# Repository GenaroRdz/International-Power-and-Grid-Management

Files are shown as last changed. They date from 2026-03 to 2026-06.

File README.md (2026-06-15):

# ⚡ Design and Implementation of Mechatronic Systems: ECU Test Bench





This repository contains all the code, hardware schematics, and assets used for the class **Design and Implementation of Mechatronic Systems**. 

The core of this project is a **High-Current Load Controller (ECU Test Bench)** designed to safely simulate, control, and monitor high-power loads (12V/5A) using solid-state switching and a custom Python Graphical User Interface (GUI).

---# ⚡ Automated HIL Power & Grid Management Unit

> **Solid-State ECU Test Bench for Automotive Hardware-In-the-Loop (HIL) Validation**

This repository contains the firmware, host software, hardware schematics, and testing assets developed for the *Design and Implementation of Mechatronic Systems* engineering capstone. 

The core of this project is a **High-Current Power Management Unit (PMU)** designed to safely automate the power cycling, control, and real-time monitoring of automotive Electronic Control Units (ECUs). By replacing traditional mechanical relays and manual resets with a fully automated, VISA-compliant Python GUI and a solid-state switching matrix, this system provides a robust framework for continuous ECU stress-testing.

## 📋 System Architecture

The architecture relies on a strict separation of concerns across three layers, safely isolating the low-voltage logic control (3.3V) from the raw automotive power stage (12V) using galvanic isolation.

1. **Host Layer (PC / Python):** A robust GUI that manages serial connection watchdogs, visualizes live telemetry on an oscilloscope, and parses automation scripts (e.g., `LOOP 10`, `DELAY 100`) into single-line SCPI/VISA string commands (`*IDN?`, `ECU1_BAT ON`).
2. **Control Layer (ESP32 / MicroPython):** An asynchronous event-driven firmware (`asyncio`) that parses commands, manages GPIO logic, polls I2C sensors, and controls the SPI CAN bus simultaneously without blocking the main loop.
3. **Hardware Layer (Custom PCB):** A 12-channel power delivery matrix protecting the logic domain from automotive 12V inrush currents and inductive spikes.

## 🚀 Key Features & Core Components

* **Solid-State Power Matrix:** Independent 12V/5A control over Battery (BAT), Accessory (ACC), and Ignition (IGN) lines across 4 distinct ECU channels.
  * *Component:* P-Channel Power MOSFETs (IRF4905) driven by PC817 Optocouplers.
* **Real-Time I2C Telemetry:** Closed-loop monitoring of voltage, current, and power consumption per channel using custom bare-metal I2C drivers.
  * *Component:* INA226 digital power monitors with ultra-low 0.01Ω shunt resistors and hardware-configured I2C addresses.
* **CAN Bus Integration:** SPI-driven CAN controller integration for broadcast messaging, ECU node-health supervision, and live traffic monitoring via the GUI.
  * *Component:* MCP2515 CAN Controller + TJA1050 Transceiver.
* **Automated Sequencer:** Custom scripting engine allowing the execution of complex testing vectors (e.g. stress tests) directly from `.txt` files.

## 📂 Repository Structure

* `/Firmware`: MicroPython scripts for the ESP32 (main asynchronous loop, custom `INA226.py` and `mcp2515.py` register-level drivers, command parser).
* `/Software`: Python GUI application (Tkinter), live scope plotting, CAN monitor, and serial management.
* `/Hardware`: KiCad schematics, wiring diagrams, LTspice validation simulations (`.asc`, `.model`), and Bill of Materials (BOM).
* `/Tests`: Example sequence `.txt` files for automated stress testing (e.g., `COMPLETE Test.txt`).
* `/Docs`: Final Technical Report, architecture diagrams, and component datasheets.

## 🛠️ Setup and Installation

### 1. Hardware Assembly
Assemble the physical circuit following the schematics provided in the `/Hardware` folder.
> ⚠️ **Safety Warning:** This system handles cumulative currents capable of exceeding 15A during inrush events. Ensure the use of appropriate gauge wiring (AWG 16 minimum) for the 12V power bus, use proper thermal dissipation techniques, and include a master inline fuse & kill-switch before the MOSFET array.

### 2. Firmware (ESP32)
1. Flash the ESP32 microcontroller with the latest MicroPython firmware.
2. Upload all python scripts from the `/Firmware` folder to the board using tools like Thonny IDE or `mpremote`.
3. The board will automatically execute `main.py` on boot, initialize the SPI/I2C buses, and await serial commands at `115200` bauds.

### 3. Software (Python GUI)
The host control interface requires **Python 3.13.x**. Navigate to the software folder and install the required dependencies:

```bash
cd Software
pip install -r requirements.txt
python main.py
```
## 📋 System Architecture

The project is modularly designed, safely isolating the low-voltage logic control (3.3V) from the raw power stage (12V) using optocouplers. 

### Core Components:
* **Microcontroller:** ESP32 running MicroPython.
* **Power Switching:** P-Channel Power MOSFET (IRF4905).
* **Current/Voltage Monitoring:** INA226 (I2C) with an ultra-low shunt resistor.
* **Isolation:** PC817 Optocoupler.
* **Simulated Load:** 120 Ohms Resistors. (in total 12 Resistors ~1.2A drawn).

---

## 📂 Repository Structure

* `/firmware`: MicroPython scripts for the ESP32 (I2C sensor reading, PWM/Digital control).
* `/software`: Python GUI application for remote monitoring and control.
* `/hardware`: Circuit schematics, wiring diagrams, and LTspice simulations (`.asc`, `.model`).
* `/docs`: Final Report, technical documentation and component datasheets (INA226, IRF4905, etc.).

---

## 🛠️ Setup and Installation

### 1. Hardware Assembly
Assemble the physical circuit following the schematics provided in the `/hardware` folder. 
> ⚠️ **Safety Warning:** This system handles currents <= 5A. Ensure the use of appropriate gauge wiring (AWG 16 minimum) for the power stage and include a master kill-switch before the MOSFET array.

### 2. Firmware (ESP32)
Flash the ESP32 with the latest MicroPython firmware. Upload the scripts from the `/firmware` folder to the board using tools like Thonny IDE or `mpremote`.

### 3. Software (Python GUI)
The control interface requires **Python 3.13.xx**. Navigate to the software folder and install the required dependencies:

```bash
cd software
pip install -r requirements.txt
python main.py

Authors:
Genaro Rodríguez Garza - A00831640 
Juan Pablo Carrasco Ferra Martínez - A01252910 
Eduardo de la Rosa Flores - A01039969 
Kleber Andres Molina Yepez - A00838725 
Jose Joaquin Rodriguez Cisneros - A00833104

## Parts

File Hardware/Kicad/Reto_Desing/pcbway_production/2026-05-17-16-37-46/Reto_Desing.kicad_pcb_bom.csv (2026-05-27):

Designator | Quantity | Value | Footprint | Package | MPN | DNP | Mount_Type | Description | KiLib_Generator | Sim.Pins
D1, D2, D3 | 3 | LED | LED_D5.0mm |  |  |  | tht | Light emitting diode | LED/THT | 1=K 2=A
J1, J2, J3, J4, J5, J6 | 6 | Conn_01x02 | JWT_A3963_1x02_P3.96mm_Vertical |  |  |  | tht | Generic connector, single row, 01x02, script generated (kicad-library-utils/schlib/autogen/connector/)
Q1, Q2, Q3 | 3 | IRF4905 | TO-220-3_Vertical |  |  |  | tht | -74A Id, -55V Vds, Single P-Channel HEXFET Power MOSFET, 20mOhm Ron, TO-220AB | package/TO_SOT/THT
R1, R10, R4, R5, R6, R9 | 6 | 330 | R_Axial_DIN0207_L6.3mm_D2.5mm_P10.16mm_Horizontal |  |  |  | tht | Resistor | resistor/THT
R11, R2, R7 | 3 | 10K | R_Axial_DIN0207_L6.3mm_D2.5mm_P10.16mm_Horizontal |  |  |  | tht | Resistor | resistor/THT
R12, R3, R8 | 3 | 120 | R_Axial_DIN0207_L6.3mm_D2.5mm_P10.16mm_Horizontal |  |  |  | tht | Resistor | resistor/THT
U1, U2, U3 | 3 | PC817 | DIP-4_W7.62mm |  |  |  | tht | DC Optocoupler, Vce 35V, CTR 50-300%, DIP-4 | package/DIP/legacy

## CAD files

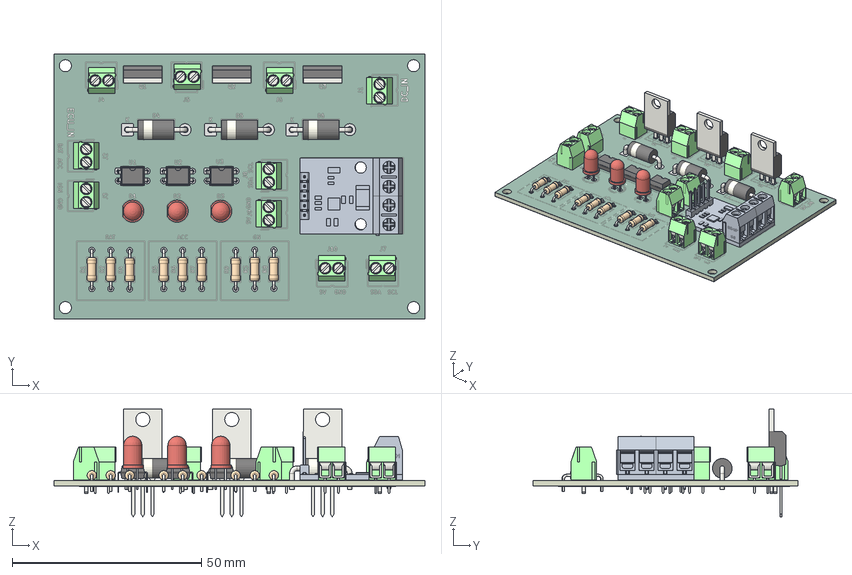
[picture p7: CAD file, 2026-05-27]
Hardware/Kicad/Reto_Desing/PCB_V2.step
98.0 x 70.0 x 28.5 mm
M1.6x4-Screw030 x 10
TO-220-3_Vertical x 3
R_Axial_DIN0207_L6.3mm_D2.5mm_P10.16mm_Horizontal x 9
LED_D5.0mm x 3
D_DO-201AD_P15.24mm_Horizontal x 3
DIP-4_W7.62mm x 3
PCB_V2 1.26.1
Reto_Desing_copper
Reto_Desing_pad
Reto_Desing_silkscreen x 2
Reto_Desing_soldermask x 2
Reto_Desing_PCB

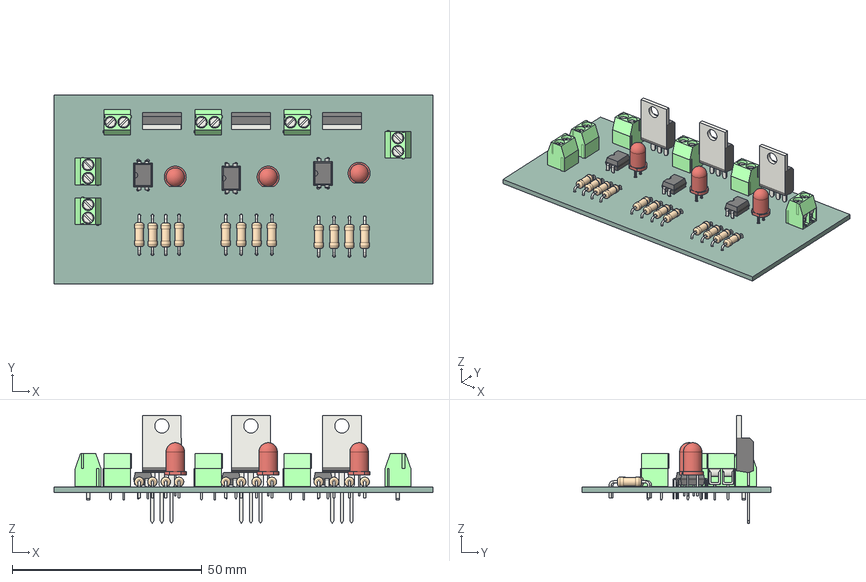
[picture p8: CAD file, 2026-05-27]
Hardware/Kicad/Reto_Desing/.step
100.0 x 50.0 x 28.5 mm
TO-220-3_Vertical x 3
R_Axial_DIN0207_L6.3mm_D2.5mm_P10.16mm_Horizontal x 12
M1.6x4-Screw030 x 6
LED_D5.0mm x 3
DIP-4_W7.62mm x 3
Reto_Desing_PCB

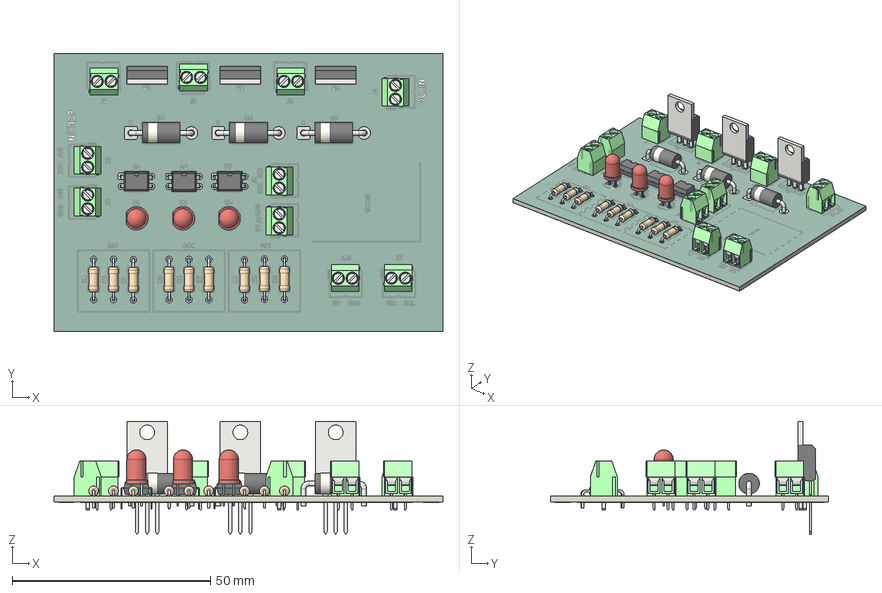
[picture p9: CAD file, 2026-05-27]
Hardware/Kicad/Reto_Desing/PCB.step
98.0 x 70.0 x 28.5 mm
M1.6x4-Screw030 x 10
TO-220-3_Vertical x 3
R_Axial_DIN0207_L6.3mm_D2.5mm_P10.16mm_Horizontal x 9
LED_D5.0mm x 3
D_DO-201AD_P15.24mm_Horizontal x 3
DIP-4_W7.62mm x 3
Reto_Desing_copper
Reto_Desing_pad
Reto_Desing_via
Reto_Desing_silkscreen x 2
Reto_Desing_soldermask x 2
Reto_Desing_PCB

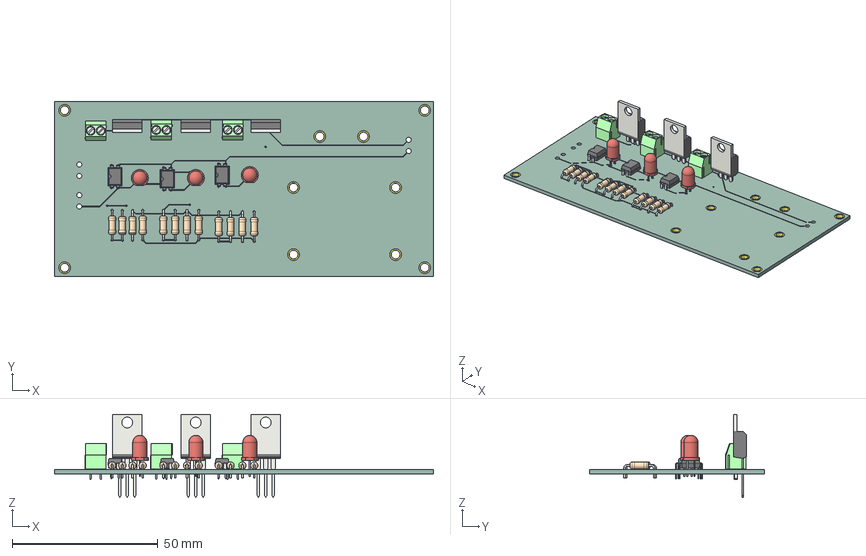
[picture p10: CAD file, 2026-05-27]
Hardware/Kicad/Reto_Desing/Pieza.step
130.0 x 60.0 x 28.5 mm
TO-220-3_Vertical x 3
R_Axial_DIN0207_L6.3mm_D2.5mm_P10.16mm_Horizontal x 12
LED_D5.0mm x 3
M1.6x4-Screw030 x 3
DIP-4_W7.62mm x 3
Reto_Desing_copper
Reto_Desing_via
Reto_Desing_PCB

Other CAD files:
Hardware/Kicad/Reto_Desing/PCB_V1.step

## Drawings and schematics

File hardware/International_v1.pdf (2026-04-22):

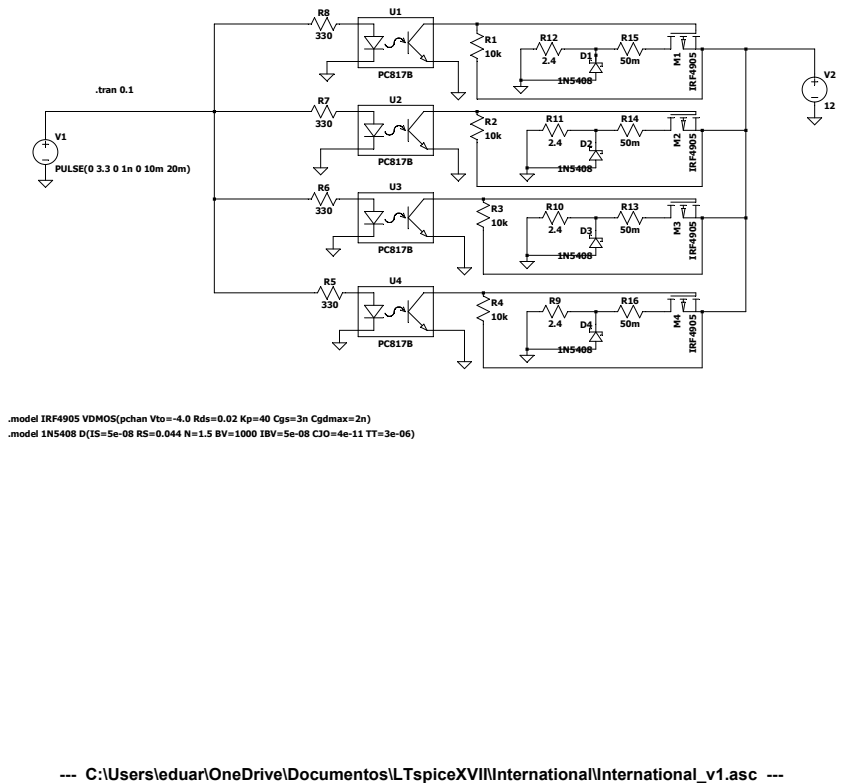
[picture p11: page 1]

2.4 M¹ IRF4905 M² IRF4905 M³ IRF4905 M⁴ IRF4905

.model IRF4905 VDMOS(pchan Vto=-4.0 Rds=0.02 Kp=40 Cgs=3n Cgdmax=2n)
.model 1N5408 D(IS=5e-08 RS=0.044 N=1.5 BV=1000 IBV=5e-08 CJO=4e-11 TT=3e-06)

--- C:\Users\eduar\OneDrive\Documentos\LTspiceXVII\International\International_v1.asc ---

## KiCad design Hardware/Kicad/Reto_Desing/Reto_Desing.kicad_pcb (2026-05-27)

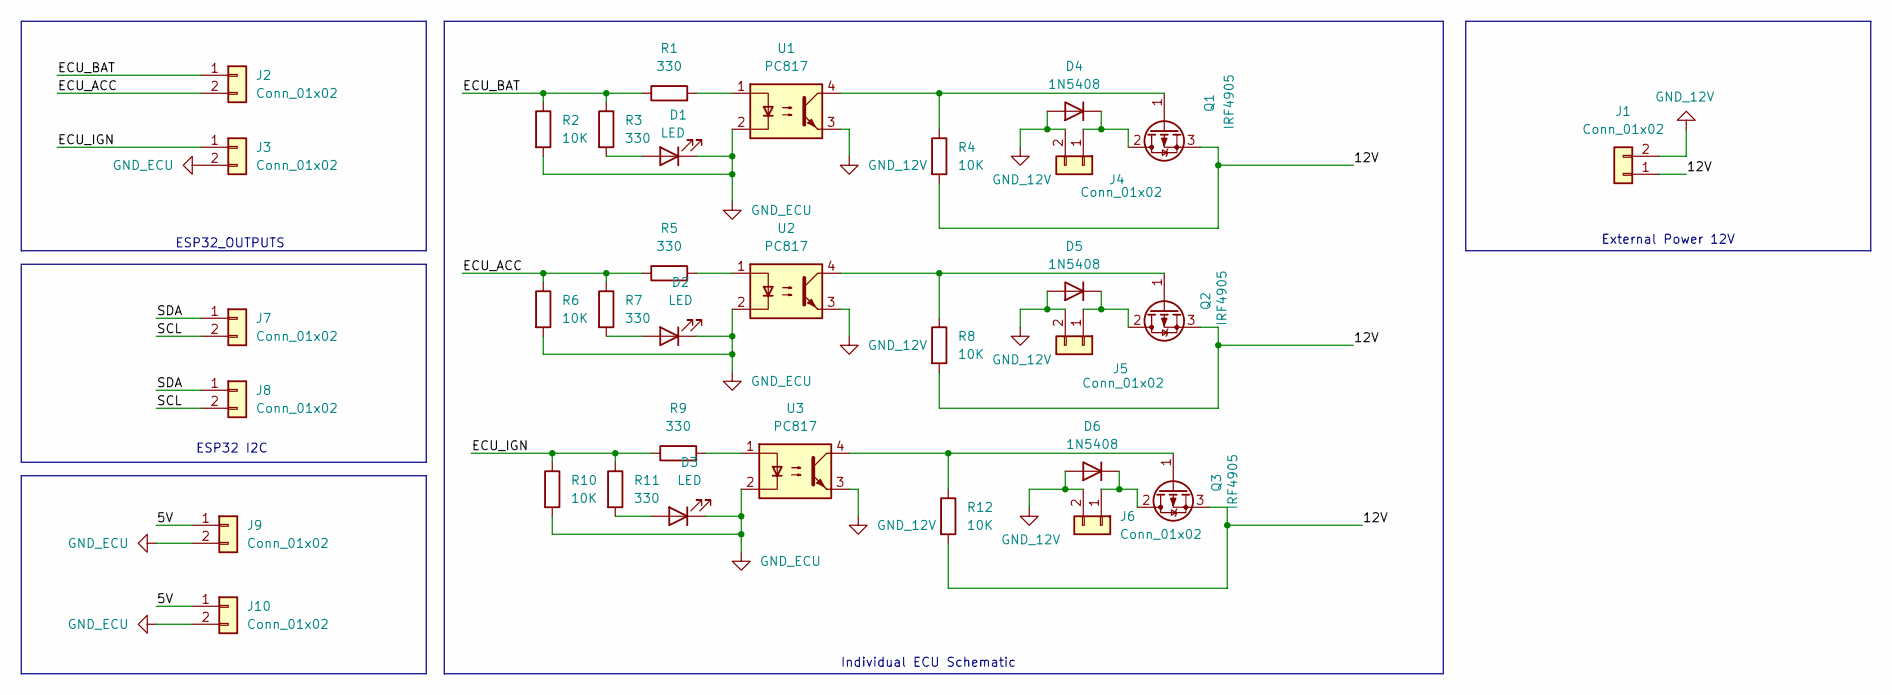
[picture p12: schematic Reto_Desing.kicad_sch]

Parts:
D1, D2, D3: LED; LED_D5.0mm
D4, D5, D6: 1N5408; D_DO-201AD_P15.24mm_Horizontal
J1, J2, J3, J4, J5, J6, J7, J8, J9, J10: Conn_01x02; JWT_A3963_1x02_P3.96mm_Vertical
Q1, Q2, Q3: IRF4905; TO-220-3_Vertical
R1, R3, R5, R7, R9, R11: 330; R_Axial_DIN0207_L6.3mm_D2.5mm_P10.16mm_Horizontal
R2, R4, R6, R8, R10, R12: 10K; R_Axial_DIN0207_L6.3mm_D2.5mm_P10.16mm_Horizontal
U1, U2, U3: PC817; DIP-4_W7.62mm

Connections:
/5V: J9.1, J10.1
/12V: J1.1, Q1.3 (S), Q2.3 (S), Q3.3 (S), R4.2, R8.2, R12.2
/ECU_ACC: J2.2, R5.1, R6.1, R7.1
/ECU_BAT: J2.1, R1.1, R2.1, R3.1
/ECU_IGN: J3.1, R9.1, R10.1, R11.1
/SCL: J7.2, J8.2
/SDA: J7.1, J8.1
GND_12V: D4.2 (A), D5.2 (A), D6.2 (A), J1.2, J4.2, J5.2, J6.2, U1.3, U2.3, U3.3
GND_ECU: D1.1 (K), D2.1 (K), D3.1 (K), J3.2, J9.2, J10.2, R2.2, R6.2, R10.2, U1.2, U2.2, U3.2
unnamed: D1.2 (A), R3.2
unnamed: D2.2 (A), R7.2
unnamed: D3.2 (A), R11.2
unnamed: D4.1 (K), J4.1, Q1.2 (D)
unnamed: D5.1 (K), J5.1, Q2.2 (D)
unnamed: D6.1 (K), J6.1, Q3.2 (D)
unnamed: Q1.1 (G), R4.1, U1.4
unnamed: Q2.1 (G), R8.1, U2.4
unnamed: Q3.1 (G), R12.1, U3.4
unnamed: R1.2, U1.1
unnamed: R5.2, U2.1
unnamed: R9.2, U3.1

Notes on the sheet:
ESP32_OUTPUTS
Individual ECU Schematic
External Power 12V
ESP32 I2C

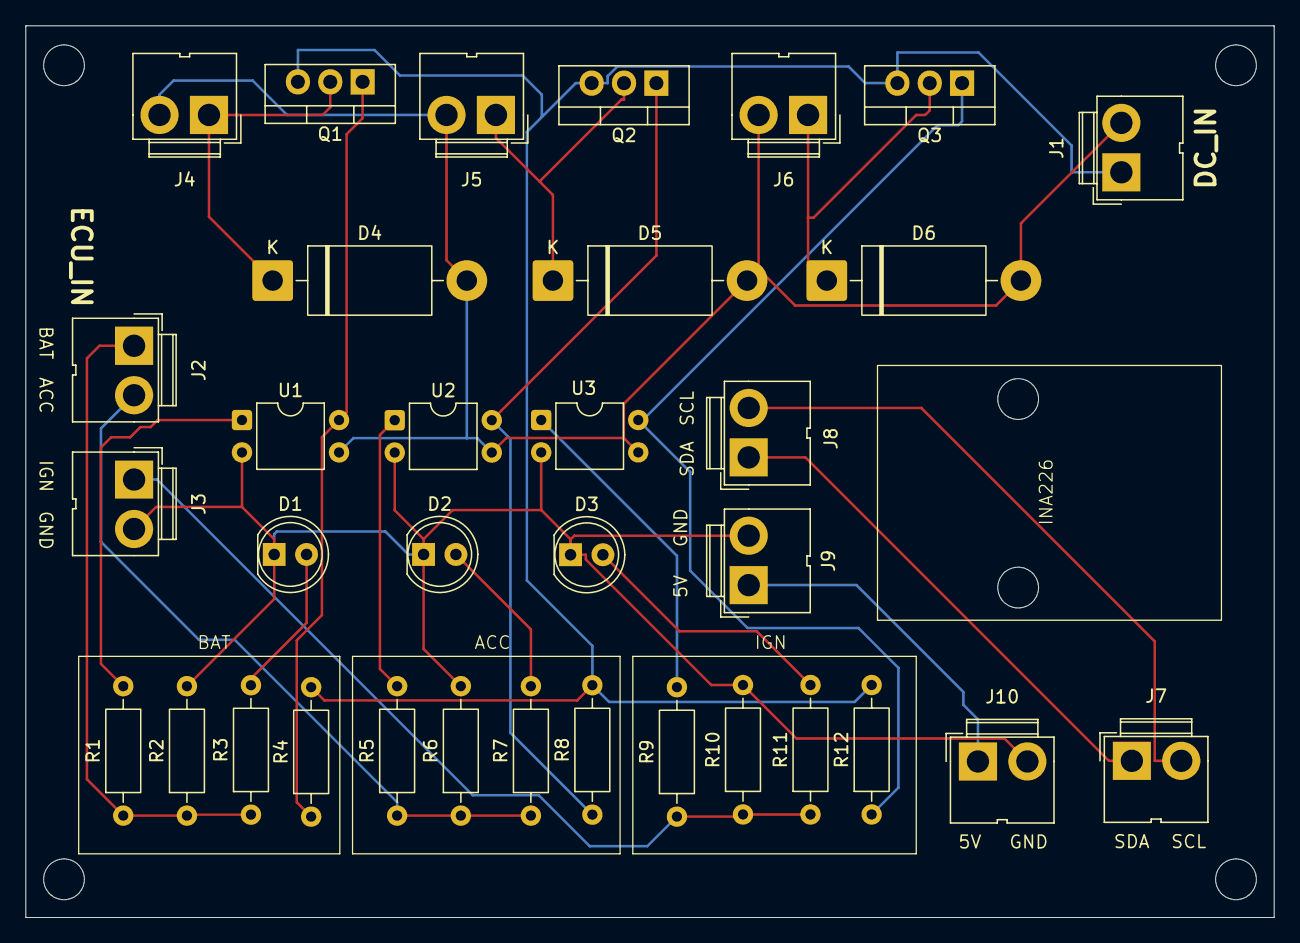
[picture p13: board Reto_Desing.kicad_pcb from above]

Board: 2 copper layers, 98.0 x 70.0 mm, 35 parts (0 on the bottom side), 21 nets.

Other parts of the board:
INA226: INA226

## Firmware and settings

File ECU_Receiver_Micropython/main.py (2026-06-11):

# main.py  --  ECU board.  (In canbus.py set  ME = "ECU1"  (or ECU2, ECU3, ECU4))

import time
from functions import send_message, receive_message
from can_setup import Current_Device

print(Current_Device, "ready (ecu)")

while True:
    msg = receive_message()
    if msg:
        sender, target, text = msg

        if target == Current_Device:                       # this command is for ME
            print("got:", text, "from", sender)

            send_message(sender, "OK")
            
        # else: it's for another ECU -- ignore it

    time.sleep_ms(10)

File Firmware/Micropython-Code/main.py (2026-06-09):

import sys
import asyncio
import setup
import functions
import INA226

# How often to push a fresh set of INA226 readings to the host, in seconds.
# 0.2 s = 5 readings per second. Raise it to stream slower, lower it for faster.
INA_PERIOD = 0.3

# How often to poll the CAN bus for incoming frames, in seconds. 0.05 s = 20x/s.
# This only LISTENS for frames addressed to / seen by this board and forwards
# them to the host as 'CANRX,...' lines. It is optional: if you only care about
# the commands MAIN sends out, you can drop can_rx_task() from the gather below.
CAN_RX_PERIOD = 0.05


async def command_task():
    sreader = asyncio.StreamReader(sys.stdin)
    while True:
        try:
            line = await sreader.readline()
            cmd = line.strip().decode()
            functions.handle_ping(cmd)
            functions.commands(cmd)
        except Exception:
            print("Commando no encontrado")


async def ina_task():
    while True:
        if functions.initialized and functions.streaming:
            try:
                print(INA226.read_all_INAs_str())
            except Exception as e:
                print("ERROR: INA read failed: {}".format(e))
        await asyncio.sleep(INA_PERIOD)


async def can_rx_task():
    # Drain any CAN frames this board received and forward them to the host as
    # 'CANRX,...' lines. Runs cooperatively with command_task on the same event
    # loop, so it never fights can_send for the SPI bus and never blocks pings.
    while True:
        try:
            functions.can_poll_rx()
        except Exception:
            pass
        await asyncio.sleep(CAN_RX_PERIOD)


async def main():
    # Reset all outputs to their default state before starting
    functions.reset()
    print("Sistema listo")
    print("BOOT")

    # Run the command listener, the INA streamer and the CAN receiver side by
    # side. To disable CAN receive, simply remove can_rx_task() from this call.
    await asyncio.gather(command_task(), ina_task(), can_rx_task())


asyncio.run(main())

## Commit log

2026-04-22 Circuit Image (pdf) upload
2026-05-27 Kicad added
    [.step, PCB.step, PCB_V1.step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]
2026-06-11 Kicad new desing
